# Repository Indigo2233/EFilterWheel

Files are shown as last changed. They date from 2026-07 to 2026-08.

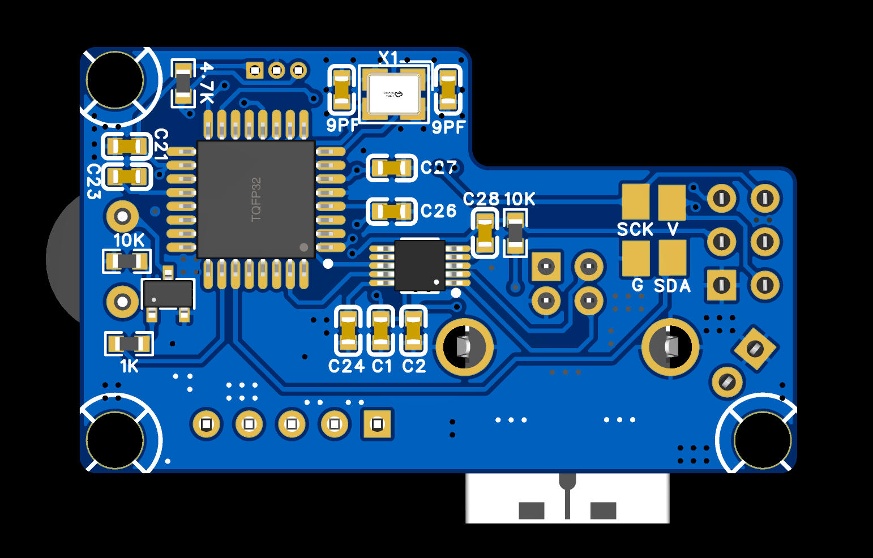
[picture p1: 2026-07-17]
ref/3、焊接参考_反面.jpg

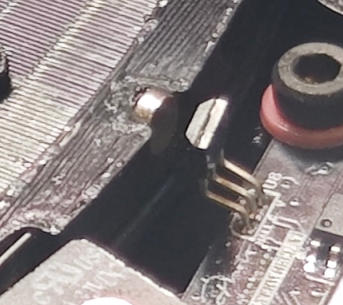
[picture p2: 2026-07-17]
ref/3、传感器安装参考.jpg

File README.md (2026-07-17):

# EFilterWheel — DIY 电动滤镜轮

基于 3D 打印结构的可重复定位电动滤镜轮，支持 Arduino Nano (USB 串口) 和 ESP8266 (Wi-Fi / ASCOM Alpaca) 两种主控配置。

## 功能

- ✅ 7 位 × 36mm 或 5 位 × 2" 滤镜盘
- ✅ 摩擦轮传动，28BYJ-48 步进电机 + ULN2003A 驱动
- ✅ 霍尔传感器原点 + 微动开关独立校验
- ✅ 上电自动回零，断电位置记忆 (EEPROM)
- ✅ 非阻塞运动控制 + 加减速
- ✅ ASCII 串口协议 (57600 baud)
- ✅ ASCOM Alpaca HTTP API (ESP8266)
- ✅ Web 控制页面 (ESP8266)
- ✅ N.I.N.A. 兼容

## 项目结构

```
EFilterWheel/
├── platformio.ini              # PlatformIO 构建配置
├── firmware/
│   ├── common/                 # 共享代码 (HAL, 运动, 滤镜轮, 协议)
│   │   ├── config.h            # 全局配置与引脚映射
│   │   ├── hal.h / hal.cpp     # 硬件抽象层
│   │   ├── motion.h / motion.cpp      # 步进电机控制
│   │   ├── wheel.h / wheel.cpp        # 滤镜轮状态机
│   │   ├── eeprom_config.h / .cpp     # EEPROM 配置存储
│   │   └── transport.h / transport.cpp # 串口/网络协议
│   ├── nano/
│   │   └── main.cpp            # Arduino Nano 入口
│   └── esp8266/
│       └── main.cpp            # ESP8266 入口 (含 Web/Alpaca)
├── tools/
│   └── serial_test.py          # PC 串口测试工具
├── docs/
│   └── protocol.md             # 协议文档
├── plan.md                     # 实施计划
└── README.md
```

## 快速开始

### 硬件要求

- 主控: Arduino Nano (ATmega328P) **或** Wemos D1 mini (ESP8266) —— 二选一
- 电机: 28BYJ-48 5V 减速步进电机
- 驱动: ULN2003A 模块
- 传感器: 霍尔开关 (开集电极输出, 如 A3144) + 微动开关
- 电源: 5V / 1A+ (建议 2A 适配器留余量)
- 蜂鸣器: Nano 可用, ESP8266 不可用 (无安全 GPIO)

### 接线 — Arduino Nano

| 功能 | Nano 引脚 | 连接至 |
|---|---|---|
| 电机 IN1 | D4 | ULN2003A IN1 |
| 电机 IN2 | D5 | ULN2003A IN2 |
| 电机 IN3 | D6 | ULN2003A IN3 |
| 电机 IN4 | D7 | ULN2003A IN4 |
| 霍尔传感器 | D2 | 霍尔 OUT (上拉至 5V) |
| 微动开关 | D3 | 开关 NO → D3, COM → GND |
| 蜂鸣器 | D8 | 蜂鸣器 + (仅 Nano) |
| LED | D13 | 板载 |

### 接线 — ESP8266 (Wemos D1 mini)

> ⚠️ **ESP8266 是 3.3V 器件，所有 GPIO 只耐受 3.3V！**
> 好消息：霍尔和微动开关都是"开漏/触点"型，**不需要电平转换芯片**，只需把上拉电阻接到 3.3V 即可。

**为什么不需要电平转换？**

```
Nano (5V) 接法:                     ESP8266 (3.3V) 接法:
                                     ⚠️ 错误:              ✅ 正确:
VCC(5V)                               VCC(5V)               VCC(5V)
  │                                      │                     │
  ├─ 4.7kΩ ──┬── GPIO(D2)               ├─ 4.7kΩ ──┬── GPIO   ├─ 霍尔 VCC(5V)
  │          │                           │          │          │
霍尔 OUT ────┘               →         霍尔 OUT ────┘        霍尔 OUT ────┬── GPIO(D7)
  │                                      │                     │          │
 GND                                    GND                    └─ 4.7kΩ ── 3.3V
                                                               │
霍尔是开集电极输出:                  上拉接 5V → GPIO 承受 5V   上拉接 3.3V → GPIO
OUT 脚只拉低,不输出高电平              ❌ 烧 GPIO!              最多承受 3.3V ✅
```

- **霍尔传感器**：开集电极（Open-Collector）输出。OUT 引脚只负责"拉低到 GND"，**高电平完全由上拉电阻的电压决定**。把上拉接到 3.3V，GPIO 就永远看不到 5V。
- **微动开关**：纯机械触点，一端接 GPIO，一端接 GND。用 3.3V 上拉，按下时读到 LOW，松开时读到 3.3V。

**实际操作：**

```
Wemos D1 mini 引脚:
                        ┌──────────────┐
                        │  3V3    GND  │ ← 用这俩
                        │  D0(16) D4(2)│
          4.7kΩ         │  D5(14) D3(0)│
3.3V ──/\/\/\/──┬── D7(13)            │
                │                      │
     霍尔 OUT ──┘                      │
                │                      │
          4.7kΩ │                      │
3.3V ──/\/\/\/──┬── D0(16)            │
                │                      │
    微动 NO ────┘                      │
                │                      │
     微动 COM ── GND                   │
                        └──────────────┘
```

- 在 D7 和 3V3 之间焊一个 4.7kΩ 电阻
- 在 D0 和 3V3 之间焊一个 4.7kΩ 电阻
- 霍尔 VCC 仍接 5V（传感器需要 5V 供电），OUT 接 D7
- 微动 NO 接 D0, COM 接 GND
- **不需要任何电平转换模块**

**引脚映射：**

| 功能 | GPIO | D1 mini 丝印 | 连接至 | 注意事项 |
|---|---|---|---|---|
| 电机 IN1 | 5 | D1 | ULN2003A IN1 | |
| 电机 IN2 | 4 | D2 | ULN2003A IN2 | |
| 电机 IN3 | 14 | D5 | ULN2003A IN3 | |
| 电机 IN4 | 12 | D6 | ULN2003A IN4 | |
| 霍尔传感器 | 13 | D7 | 霍尔 OUT | **必须接 3.3V 上拉电阻 (4.7kΩ)** |
| 微动开关 | 16 | D0 | 开关 NO → D0, COM → GND | **必须接外部 3.3V 上拉电阻** |
| LED | 2 | D4 | 板载 | 板载 LED, 低电平点亮 |
| 蜂鸣器 | — | — | **不接** | GPIO15(D8) 启动需 LOW, 无安全引脚可用 |

**电平处理要点：**

- **霍尔传感器**：VCC 接 **5V**（传感器供电），OUT 接 GPIO，上拉电阻接 **3.3V**
- **微动开关**：GPIO16 无内部上拉，外加 4.7kΩ 到 3.3V
- **ULN2003A**：数据手册输入高电平阈值 ≥ 2.4V，ESP8266 的 3.3V GPIO 满足要求；若驱动力不足可将 COM 端接 5V
- **不需要额外的电平转换芯片或分压电路**

**GPIO 启动约束（必须遵守）：**

| GPIO | 启动要求 | 当前用途 | 安全性 |
|---|---|---|---|
| GPIO0 (D3) | 必须 HIGH | 未使用 | ✅ |
| GPIO2 (D4) | 必须 HIGH | 板载 LED (已有上拉) | ✅ |
| GPIO15 (D8) | 必须 LOW | 未使用 | ✅ |
| GPIO16 (D0) | 无约束 | 微动开关输入 | ✅ |

### ESP8266 焊接步骤

参考图片：`ref/3、焊接参考_正面.jpg` 和 `ref/3、焊接参考_反面.jpg`

1. **先焊贴片、后焊插件** — 优先焊完所有贴片元件，再处理直插元件
2. **电机插座** — 5Pin 带锁插座，注意方向避免反插
3. **传感器连接** — 霍尔用 2Pin/3Pin 带锁插座；微动开关引脚可压弯
4. **上拉电阻** — 在霍尔和微动开关旁边就近焊接 4.7kΩ 上拉电阻到 3.3V
5. **不要焊蜂鸣器** — 无安全 GPIO
6. **电容** — 未标注容值的均为 100nF；电机驱动旁路电容 100~470µF
7. **保险丝** — 自恢复保险丝可选但建议焊接；不焊则短接焊盘
8. **TVS/肖特基二极管** — 丝印有横杠的一端为负极，对齐 PCB 丝印
9. **固定螺丝** — 轻微拧紧即可，务必放垫片防止磨损 PCB
10. **上电前检查** — 用万用表确认所有传感器引脚电压 ≤ 3.3V

### 编译与烧录

**PlatformIO**:

```bash
# Arduino Nano
pio run -e nano -t upload

# ESP8266
pio run -e esp8266 -t upload

# 串口监视
pio device monitor -b 57600
```

**Arduino IDE**:

1. 将 `firmware/common/` 中的 `.cpp` 和 `.h` 文件复制到 Sketch 目录
2. Nano: 将 `firmware/nano/main.cpp` 重命名为 `.ino` 并打开
3. ESP8266: 将 `firmware/esp8266/main.cpp` 重命名为 `.ino`，需安装 ESP8266 板支持包
4. 选择对应板型: Nano (ATmega328P) 或 Wemos D1 R1
5. 编译并上传

### 首次使用

1. 上电后设备自动开始回零
2. 串口终端 (57600 baud) 发送 `ID?` 验证通信
3. 发送 `STATE?` 确认状态为 `READY`
4. 发送 `GOTO 0` 移动到第一个槽位

### 标定

每台设备需要独立标定，因为打印收缩率和电机减速比存在差异：

```bash
# 设置滤镜盘槽位数
SLOTS 7

# 标定各槽位步数（从原点起算）
CAL SLOT 0 0
CAL SLOT 1 512
CAL SLOT 2 1024
# ...

# 保存配置
SAVE
```

## ESP8266 网络功能

ESP8266 首次上电时启动 AP 模式用于 Wi-Fi 配置：

1. 连接 WiFi `EFilterWheel-Setup` (密码: `filterwheel`)
2. 浏览器访问 `http://192.168.4.1/wifi`
3. 输入路由器 SSID 和密码
4. 设备重启后自动连接

设备就绪后：
- Web 控制: `http://<ip>/`
- Alpaca API: `http://<ip>/api/v1/filterwheel/0/`
- mDNS: `http://efilterwheel.local/`

## 许可证

本项目代码基于参考项目的非商业授权许可。个人制作、学习和非营利协作可按许可进行。商业用途需取得原作者书面授权。

原始项目作者: Eric (微信: ericbo)

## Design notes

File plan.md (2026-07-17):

# ESP8266 / Arduino Nano 电动滤镜轮实施计划

更新日期：2026-07-17  
参考资料：`E:\download\滤镜轮项目开源资料`

## 1. 项目目标

基于现有 3D 打印结构制作一套可重复定位的电动滤镜轮，支持以下两种主控构建配置：

- Arduino Nano：用于首个样机，通过 USB 串口连接计算机，优先完成机械、传感器和运动控制验证。
- ESP8266：用于网络控制版本，复用同一套运动控制逻辑，增加 Web 配置及 ASCOM Alpaca 接口。

两种主控为互斥配置，每台成品安装其中一种。首轮目标采用 Arduino Nano，原因是其 5 V I/O、USB 串口和原结构中的 ULN2003A/5 线步进电机组合适配度较高。

项目完成时应交付：

1. 可装配的机械结构及打印参数。
2. 原理图、接线图、BOM 和主控安装方案。
3. Arduino Nano 与 ESP8266 两个固件构建目标。
4. USB 串口控制协议及 ESP8266 网络接口。
5. ASCOM/Alpaca 兼容层和 N.I.N.A. 联调记录。
6. 校准、装配、烧录、故障处理和测试文档。

## 2. 已确认的参考基线

### 2.1 机械模型

| 模型 | 已提取外形尺寸 | 用途与检查重点 |
| --- | --- | --- |
| `7x36mm滤镜盘.STL` | 143 × 143 × 7 mm | 7 位、36 mm 滤镜；核对槽位中心与传感触发结构 |
| `5×2“滤镜盘.stl` | 143 × 143 × 7 mm | 5 位、2 英寸滤镜；核对滤镜实际外径和压环 |
| `外壳.STL` | 158 × 182.23 × 17 mm | 检查盘体间隙、遮光和主控空间 |
| `后盖.STL` | 158 × 182.59 × 5 mm | 检查螺丝长度、线束和主控高度 |
| `电机盖.STL` | 49.05 × 43.03 × 23 mm | 检查电机、接插件和线束空间 |
| `滤镜压环.STL` | 128.34 × 128.32 × 1 mm | 检查滤镜固定和翘曲 |
| `传动轮2_D轴.STL` | 11 × 11 × 8 mm | D 形电机轴适配候选 |
| `传动轮2_D14` 至 `D17` | 外径 14–17 mm，高 8 mm | 补偿打印收缩与摩擦圈预紧量 |
| `防脱压片.stl` | 33 × 33 × 3 mm | 中心轴防脱和轴向间隙控制 |
| `PCB螺丝垫片.STL` | 4.8 × 4.8 × 1 mm | 防止 PCB 与打印件接触磨损 |

参考 3MF 的现有切片参数为：PLA、0.4 mm 喷嘴、0.2 mm 层高、2 道墙、15% 网格填充、5 层顶面、3 层底面、关闭支撑、5 mm 自动裙边。首个尺寸样件沿用这组参数，传动轮应分别打印多个直径版本进行实配。

### 2.2 原结构的机电特征

根据项目介绍、内部结构图和焊接参考图，当前基线包含：

- 5 线单极步进电机和 ULN2003A 驱动阵列，具体电机型号及线圈参数需通过 BOM 和实物测量确认。
- 摩擦轮传动，传动轮通过橡胶圈压紧滤镜盘外缘。
- 一个霍尔传感器和一个磁铁，磁铁安装要求为 S 极朝外。
- 一个微动开关，预期用于槽位触发或独立位置校验，其实际触发规律应在手动旋转滤镜盘时记录。
- USB 接口、蜂鸣器、电源保护器件和 5 线电机插座。
- 上电初始化、位置检测和 ASCOM 控制属于原项目已说明的功能。

### 2.3 使用许可

参考资料采用仅限非商业用途的自定义许可。个人制作、学习和非营利协作可按许可进行；再发布模型、固件或修改版本时必须保留原许可与作者版权信息。商业用途需要取得作者书面授权。

## 3. 总体技术方案

```text
5 V 输入
  ├─ 保险/反接保护/TVS/滤波
  ├─ 主控：Arduino Nano 或 ESP8266
  └─ ULN2003A → 5 线步进电机 → 摩擦轮 → 滤镜盘

霍尔传感器 ──→ 原点输入
微动开关   ──→ 槽位索引或独立校验输入
USB 串口   ──→ Nano 控制协议 ──→ ASCOM 兼容层
Wi-Fi      ──→ ESP8266 HTTP/Alpaca 接口
```

固件分为四层：

1. `hal`：GPIO、定时器、EEPROM、串口和网络适配。
2. `motion`：步进序列、加减速、方向、超时和断电释放。
3. `wheel`：回零、槽位换算、误差补偿、状态机和故障处理。
4. `transport`：串口命令、Web 配置和 Alpaca API。

运动状态统一定义为 `BOOT`、`HOMING`、`READY`、`MOVING`、`ERROR`。所有移动操作均应设置最大步数和超时时间，故障状态应立即停止脉冲并释放电机线圈。

## 4. 电气设计计划

### 4.1 首轮器件基线

- 主控：Arduino Nano ATmega328P 兼容板。
- 网络主控候选：Wemos D1 mini 或同尺寸 ESP8266 开发板，最终型号由安装空间决定。
- 电机：参考原结构的 5 V、5 线减速步进电机候选，优先核对是否为 28BYJ-48 及其减速比。
- 驱动：ULN2003A 模块或自制小板；ESP8266 配置需实测 3.3 V 输入驱动余量。
- 原点传感器：开集电极霍尔开关候选，具体型号以原 BOM/丝印为准。
- 位置传感器：常开或常闭微动开关，先测定原机械触发方式。
- 电源：稳压 5 V、持续电流至少 1 A，建议预留 2 A 电源适配器余量。
- 保护与滤波：自恢复保险丝、反接保护、TVS、主控附近 100 nF 去耦和电机驱动附近 100–470 µF 储能电容。
- 连接：电机采用带锁 5Pin 插座，传感器采用带锁 2Pin/3Pin 插座，避免装配时反插。

### 4.2 候选引脚分配

Arduino Nano：

| 功能 | 引脚 | 说明 |
| --- | --- | --- |
| 霍尔原点 | D2 | 外部中断、内部或外部上拉 |
| 微动开关 | D3 | 外部中断、软硬件消抖 |
| 电机 IN1–IN4 | D4–D7 | 连接 ULN2003A |
| 蜂鸣器 | D8 | 通过限流或三极管驱动 |
| 状态灯 | D13 | 使用板载 LED |
| USB 串口 | D0/D1 | 仅用于板载 USB 串口，不接其他负载 |

ESP8266 候选：

| 功能 | GPIO | 说明 |
| --- | --- | --- |
| 电机 IN1–IN4 | 5、4、14、12 | 对应常见 D1、D2、D5、D6 标记 |
| 霍尔原点 | 13 | 中断输入，使用 3.3 V 上拉 |
| 微动开关 | 16 | 轮询输入并进行消抖 |

ESP8266 的传感器输入电压必须限制在 3.3 V。若霍尔器件为开集电极输出，将上拉电阻接至 3.3 V；若输出结构或型号无法确认，应增加分压、钳位或电平转换。GPIO0、GPIO2 和 GPIO15 与启动模式有关，首版接线应避免传感器改变其上电电平。

### 4.3 原理样机检查

1. 在滤镜轮外部搭建电机、ULN2003A 和主控。
2. 测量单相、双相和堵转时的 5 V 电流及主控电压跌落。
3. 确认电机线序、转向、半步序列、最大可靠速度和启动速度。
4. 分别测量霍尔传感器有磁/无磁电平，确认磁铁极性和有效距离。
5. 记录微动开关在完整一圈内的触发次数、触发宽度和对应槽位。
6. 验证电机停机后释放线圈不会导致滤镜盘自行偏移。

## 5. 机械实施计划

### 阶段 M1：模型复核

1. 确定首个滤镜盘版本，默认采用 `7x36mm滤镜盘.STL`。
2. 在切片软件中检查所有模型的单位、法向、薄壁、孔径和打印方向。
3. 测量现有电机轴、橡胶圈、磁铁、微动开关、螺丝和滤镜的实际尺寸。
4. 先打印 D14–D17 传动轮、PCB 垫片和一段局部配合测试件。
5. 选定能够稳定传动且不会显著压缩橡胶圈的传动轮尺寸。

### 阶段 M2：空载装配

1. 打印外壳、后盖、电机盖、滤镜盘、防脱压片和压环。
2. 安装空滤镜盘，调整中心轴向间隙，使盘体能够手动平稳旋转。
3. 检查盘体全周与外壳、后盖、螺丝、传感器和线束的间隙。
4. 调整电机位置和摩擦轮预紧量，记录可重复的装配尺寸。
5. 确定 Nano 与 ESP8266 各自的安装支架、USB 开口和走线方案。

### 阶段 M3：负载装配

1. 安装测试配重或低价值滤镜，检查盘体翘曲和压环受力。
2. 完成所有槽位的光轴中心校验。
3. 对外壳接缝、USB 开口和螺丝孔实施遮光检查。
4. 通过连续换位试验确认橡胶圈无打滑、啃边和明显磨耗。

## 6. 固件实施计划

### 阶段 F1：电机与传感器最小程序

- 实现 4 相半步驱动表、方向控制和非阻塞定时步进。
- 实现速度参数、启动斜坡和停机线圈释放。
- 输出霍尔和微动开关原始状态、消抖状态及触发计数。
- 提供安全停止和移动超时。

### 阶段 F2：回零与槽位标定

- 上电进入 `HOMING`，以低速搜索霍尔原点。
- 首次触发后退出传感区，再以更低速度二次接近，减少回零方向误差。
- 测量完整一圈的总步数和各槽位对应步数，分别保存 5 位、7 位配置。
- 记录微动开关触发点与霍尔原点的关系，确定其作为逐槽索引或独立校验信号的用途。
- 将槽位数、原点偏移、方向、速度、超时及补偿参数保存到 EEPROM，并附带版本号和校验值。

### 阶段 F3：定位算法与状态机

- 实现 `gotoSlot(n)`，支持 5 位和 7 位盘体。
- 计算顺时针和逆时针路径，默认采用较短路径。
- 通过固定方向终到或受控过冲回退处理齿隙、摩擦回差和开关迟滞，最终方案由重复定位数据决定。
- 在运动中报告忙状态，完成后报告实际槽位；传感异常、超时和步数越界进入 `ERROR`。
- 上电、复位、通信重连后执行可配置的回零流程。
- 启用看门狗，并确保 ESP8266 在电机运动期间持续让出网络任务执行时间。

### 阶段 F4：统一控制协议

定义换行结束的 ASCII 协议，首版命令如下：

| 命令 | 作用 |
| --- | --- |
| `ID?` | 返回设备、固件和协议版本 |
| `STATE?` | 返回 `HOMING/READY/MOVING/ERROR` 及错误码 |
| `POS?` | 返回当前槽位；移动中返回 `-1` |
| `HOME` | 启动回零 |
| `GOTO n` | 移动到从 0 开始编号的槽位 |
| `STOP` | 安全停止并进入需确认的状态 |
| `SLOTS 5` / `SLOTS 7` | 设置滤镜盘槽位数 |
| `CAL ...` | 设置或查询标定参数 |
| `SAVE` | 保存有效配置 |

响应格式统一为 `OK ...` 或 `ERR <code> <message>`。Nano 默认串口参数先采用参考项目使用的 57600 baud，完成稳定性测试后冻结协议版本。

### 阶段 F5：ESP8266 网络功能

- 实现 Wi-Fi 初次配置、凭据保存、断线重连和恢复出厂设置。
- 提供本地状态页、手动回零、槽位选择和标定参数页面。
- 将 HTTP 请求转入同一运动状态机，禁止网络回调直接驱动电机。
- 实现 ASCOM Alpaca FilterWheel 所需接口及设备发现。
- 保留串口日志，并提供网络故障时的本地控制入口。

## 7. 上位机与天文软件兼容计划

### 7.1 Arduino Nano 路线

1. 先制作串口测试工具或命令行脚本，覆盖所有命令和错误码。
2. 明确原项目 ASCOM 驱动的串口协议；可兼容时复用协议，不兼容时开发新的 ASCOM FilterWheel 驱动或本地 Alpaca 桥接程序。
3. 在 N.I.N.A. 中验证连接、回零、槽位切换、序列切换和异常恢复。

### 7.2 ESP8266 路线

1. 按 ASCOM Alpaca FilterWheel 接口实现 `Names`、`FocusOffsets` 和 `Position` 等必要成员。
2. 槽位编号使用 0 到 N−1；运动期间 `Position` 返回 `-1`，完成后返回实际槽位。
3. 验证设备发现、并发查询、重复命令、网络中断和主控复位场景。

ASCOM 当前的 COM 与 Alpaca 主接口采用相同的设备语义，FilterWheel 的位置写入应异步启动运动，客户端通过 `Position == -1` 判断移动状态。实现时以官方规范为准：

- https://ascom-standards.org/newdocs/
- https://ascom-standards.org/newdocs/filterwheel.html
- https://ascom-standards.org/AlpacaDeveloper/ASCOMAlpacaAPIReference.html

## 8. 验证与验收标准

### 8.1 台架测试

- 电机连续正反转各 30 分钟，无主控复位、驱动过热和持续丢步。
- 霍尔传感器与微动开关各触发 500 次，无漏触发和重复计数。
- 任意角度启动回零 50 次，成功率 100%。
- 移动超时、传感器常开、传感器常闭和电机断线均产生明确错误码。

### 8.2 整机定位测试

- 5 位或 7 位全部槽位往返切换至少 200 个完整循环。
- 每个槽位从两个方向到达后，滤镜孔相对光轴中心偏差目标值不超过 0.5 mm。
- 测试过程中不允许出现摩擦轮打滑、滤镜盘刮擦和紧固件松动。
- 相邻槽位切换时间目标值不超过 10 秒；最终指标依据电机减速比和可靠速度实测冻结。
- 上电到完成回零的目标时间不超过 30 秒。
- 停机 30 分钟后电机、驱动器和主控温升处于器件允许范围，并记录实测温度。

### 8.3 通信测试

- USB 插拔、串口占用、错误命令和连续快速查询不会导致固件失去响应。
- ASCOM/N.I.N.A. 连续执行 100 次槽位切换，槽位显示与实际位置一致。
- ESP8266 经过 Wi-Fi 断开、路由器重启和 DHCP 地址变化后能够自动恢复。
- 运动过程中网络请求保持可响应，所有重复请求具有确定行为。

## 9. 分阶段交付与退出条件

| 阶段 | 主要产物 | 退出条件 |
| --- | --- | --- |
| P0 资料与需求冻结 | 选型记录、尺寸表、原 BOM 复核结果 | 确定滤镜盘版本、主控首选、电机型号和传感器逻辑 |
| P1 台架电气样机 | 接线图、电流/电平记录、最小测试程序 | 电机与两个传感器稳定运行 |
| P2 Nano 运动固件 | 回零、定位、协议、EEPROM 配置 | 空载定位测试通过 |
| P3 机械整机 | 完整打印件、安装支架、装配记录 | 负载 200 循环测试通过 |
| P4 USB 软件兼容 | 串口工具、ASCOM 兼容层、联调记录 | N.I.N.A. 自动序列切换通过 |
| P5 ESP8266 版本 | 网络配置、Web 页面、Alpaca 服务 | 网络恢复及 Alpaca 测试通过 |
| P6 定版 | BOM、原理图、固件发布包、制作说明 | 全部验收项目完成并保留许可信息 |

## 10. 主要风险与处理措施

| 风险 | 影响 | 处理措施 |
| --- | --- | --- |
| 原 BOM 尚未完成单元格级复核 | 电机、霍尔器件和保护元件型号存在偏差 | 在 P0 使用可控的表格读取工具复核 BOM，并用实物丝印和电气测量交叉确认 |
| 摩擦轮预紧量不稳定 | 打滑、磨耗、定位误差 | 打印 D14–D17 多个版本，记录压缩量，建立固定电机安装尺寸 |
| 5 线电机减速比存在批次差异 | 每圈步数和速度不一致 | 每台设备执行整圈标定，参数写入 EEPROM |
| 微动开关用途判断错误 | 槽位计数逻辑失效 | 手动旋转一周记录波形，再冻结传感器职责 |
| ESP8266 3.3 V 电平与原 5 V 传感器不兼容 | GPIO 损坏或误触发 | 使用 3.3 V 上拉、电平转换和输入保护，装机前测量所有输入电压 |
| 电机电流引起主控复位 | 丢失位置和网络断线 | 星形供电、驱动端储能电容、去耦、线束分离和电压跌落测试 |
| 打印收缩与盘体翘曲 | 摩擦增大、光轴偏移 | 先打印测试件，必要时提高墙数、调整材料和打印方向 |
| 网络控制功能占用实时执行时间 | 步进不均匀或看门狗复位 | 使用定时调度、非阻塞状态机和短网络回调 |
| 参考资料为非商业许可 | 再发布或用途受限 | 保留许可和版权声明，商业计划启动前取得书面授权 |

## 11. 实施前需要冻结的选择

以下默认值可直接进入 P0：

- 首个机械版本：7 × 36 mm 滤镜盘。
- 首个主控：Arduino Nano。
- 首个连接方式：USB 串口，57600 baud。
- 电机基线：5 V、5 线减速步进电机，型号在 P0 复核。
- 传感方案：霍尔原点加微动开关独立校验。
- 网络版本：完成 Nano 整机验收后移植至 ESP8266。

如果实际目标为 5 × 2 英寸滤镜、仅需 Wi-Fi 控制、需要兼容现有原版 ASCOM 驱动，或已经购买了特定电机/开发板，应在 P0 开始时更新上述选择。

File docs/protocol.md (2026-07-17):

# EFilterWheel 串口控制协议 v1.0

## 概述

EFilterWheel 使用基于换行 (`\n`) 分隔的 ASCII 文本协议进行串口通信。

- **物理层**: UART, 57600 baud, 8N1
- **命令格式**: `CMD [args]\n`
- **响应格式**: `OK [data]\n` 或 `ERR <code> <message>\n`
- **编码**: UTF-8

## 设备状态

| 状态 | 含义 | 可接受命令 |
|---|---|---|
| `BOOT` | 启动中 | 无 |
| `HOMING` | 回零中 | `STATE?`, `POS?`, `ID?`, `STOP` |
| `READY` | 就绪 | 全部命令 |
| `MOVING` | 移动中 | `STATE?`, `POS?`, `ID?`, `STOP` |
| `ERROR` | 错误 | `STATE?`, `ID?`, `RESET` |

## 命令参考

### ID? — 查询设备信息

```
> ID?
< OK EFilterWheel-Nano FW:1.0.0 PROTO:1.0
```

### STATE? — 查询设备状态

```
> STATE?
< OK READY ERR:0
```

错误码为 0 表示无错误，其他值见错误码表。

### POS? — 查询当前槽位

```
> POS?
< OK 2
```

- `0..N-1`: 当前槽位号（从 0 开始）
- `-1`: 移动中
- `-2`: 未回零

### HOME — 启动回零

```
> HOME
< OK HOMING started
  ... (等待中)
< OK HOMED
```

回零过程：
1. 快速搜索霍尔传感器
2. 首次触发后退出传感区
3. 低速二次精调接近

回零超时默认 60 秒。

### GOTO n — 移动到槽位 n

```
> GOTO 3
< OK GOTO 3
```

- 槽位从 0 开始编号
- 自动选择最短路径
- 移动超时默认 30 秒

### STOP — 紧急停止

```
> STOP
< OK STOPPED
```

停止后设备进入 `ERROR` 状态，需要重新回零。

### SLOTS 5|7 — 设置滤镜盘槽位数

```
> SLOTS 5
< OK SLOTS=5
```

### CAL — 标定参数管理

查询当前标定：

```
> CAL?
< OK SLOTS:7 SPEED:800 DIR:CW INVERT:0 S0:0 S1:512 S2:1024 ...
```

设置槽位步数：

```
> CAL SLOT 1 500
< OK CAL SLOT 1 = 500
```

设置速度：

```
> CAL SPEED 1000
< OK CAL SPEED=1000
```

设置方向：

```
> CAL DIR CW
< OK CAL DIR=CW
```

设置原点偏移：

```
> CAL OFFSET 10
< OK CAL OFFSET=10
```

### SAVE — 保存配置到 EEPROM

```
> SAVE
< OK SAVED
```

### RESET — 重启设备

```
> RESET
< OK RESET - Rebooting...
```

### HELP — 显示命令帮助

```
> HELP
< OK Commands:
<   ID?        - Device info
<   STATE?     - Device state
  ...
< OK End of help
```

## 错误码

| 码 | 名称 | 说明 |
|----|---|---|
| 0 | ERR_NONE | 无错误 |
| 1 | ERR_UNKNOWN_CMD | 未知命令 |
| 2 | ERR_BAD_ARG | 参数错误 |
| 3 | ERR_NOT_READY | 设备未就绪 |
| 4 | ERR_BUSY | 设备忙 |
| 5 | ERR_HOMING_FAILED | 回零失败 |
| 6 | ERR_TIMEOUT | 移动超时 |
| 7 | ERR_SENSOR_FAULT | 传感器故障 |
| 8 | ERR_EEPROM_FAIL | EEPROM 故障 |
| 9 | ERR_INVALID_CONFIG | 无效配置 |
| 10 | ERR_MOTOR_FAULT | 电机故障 |
| 11 | ERR_STOPPED | 已停止 |
| 12 | ERR_OUT_OF_RANGE | 槽位超出范围 |
| 99 | ERR_INTERNAL | 内部错误 |

## ASCOM 兼容性

对于 Arduino Nano + USB 串口连接，可以通过 ASCOM 串口驱动或 Alpaca 桥接程序连接到 N.I.N.A.。

对于 ESP8266 版本，设备直接提供 ASCOM Alpaca FilterWheel HTTP API：

```
GET  /api/v1/filterwheel/0/position
PUT  /api/v1/filterwheel/0/position  (body: slot number)
GET  /api/v1/filterwheel/0/names
GET  /api/v1/filterwheel/0/focusoffsets
GET  /api/v1/filterwheel/0/connected
GET  /api/v1/filterwheel/0/interfaceversion
GET  /api/v1/filterwheel/0/driverinfo
```

Alpaca 设备发现通过 mDNS (`efilterwheel.local`) 实现。

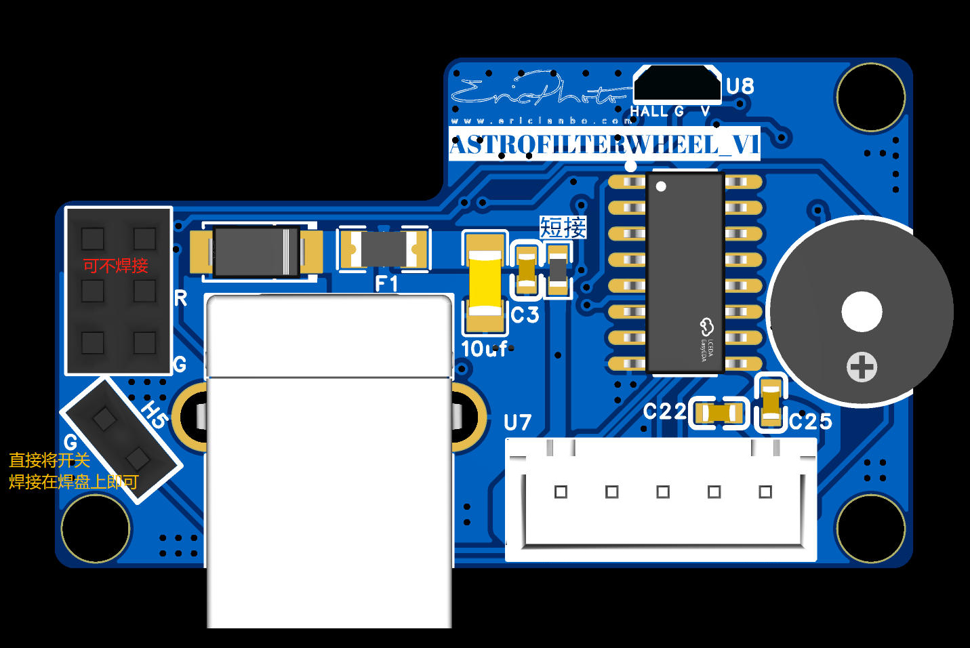
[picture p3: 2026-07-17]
ref/3、焊接参考_正面.jpg

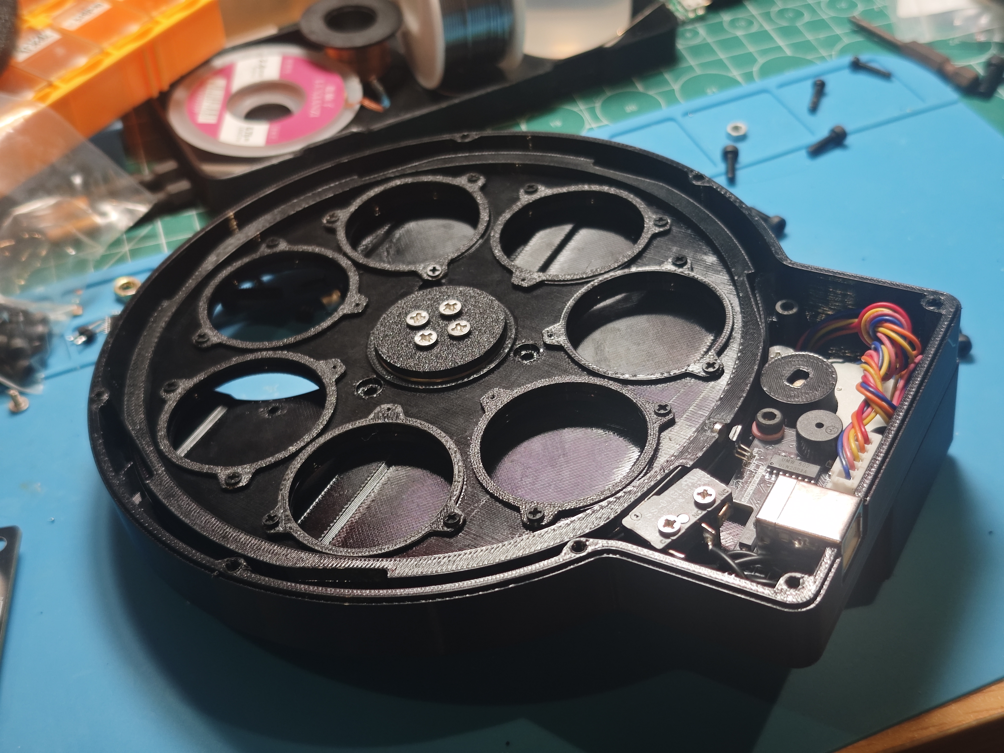
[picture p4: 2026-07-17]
ref/3、实物内部参考.jpg

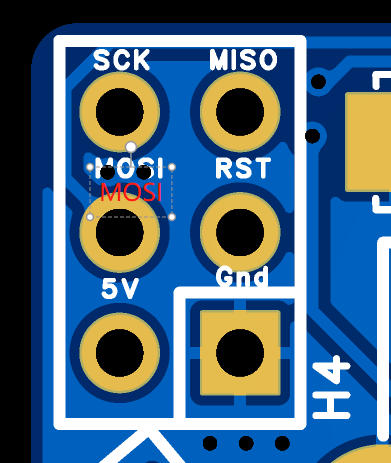
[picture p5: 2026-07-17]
ref/3、ISP烧录引脚参考.jpg

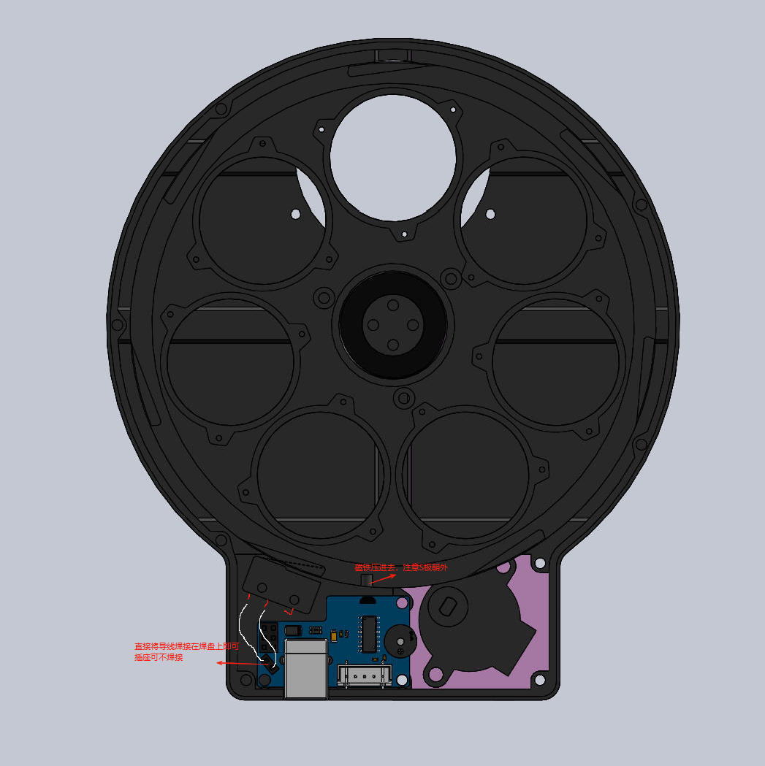
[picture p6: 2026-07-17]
ref/3、内部结构参考.jpg

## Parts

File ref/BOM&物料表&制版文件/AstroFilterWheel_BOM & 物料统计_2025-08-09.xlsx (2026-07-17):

No. |  | Quantity | Comment | Designator | Footprint
1 |  | 1 | 1K | 1K | R0603
2 |  | 1 | 4.7K | 4.7K | R0603
3 |  | 2 | 22pF | 9PF,9PF | C0603
4 |  | 1 | 10K | 10K | R0603
5 |  | 1 | 10kΩ | 10K | R0603
6 |  | 1 | 10UF | 10uf | C1206 | 0.5
7 |  | 1 | 3kHz | BUZZER1 | BUZ-TH_BD9.0-P5.00-D0.6-FD | 0.5
8 |  | 11 | 100nF | C1,C2,C3,C21,C22,C23,C24,C25,C26,C27,C28 | C0603 | 0.1
9 | 可不买 | 1 | SMD1206-150-16 | F1 | F1206 | 0.2
10 | 可不买 | 1 | 2.54mm2x3直排母 | H4 | HDR-TH_6P-P2.54-V-F-R2-C3-S2.54
11 |  | 1 | S8050 J3Y | Q1 | SOT-23-3_L3.0-W1.7-P0.95-LS2.9-BR
12 |  | 3 | M3螺丝 | SCREW1,SCREW2,SCREW3 | M3螺丝
13 | 可不买 | 1 | SMAJ6.0A-JSM | TVS1 | SMA_L4.3-W2.6-LS5.2-RD | 0.1
14 |  | 1 | ULN2003 | U4 | SOIC-16_L9.9-W3.9-P1.27-LS6.0-BL | 0.3
15 |  | 1 | ATMEGA328P-AU | U5 | TQFP-32_L7.0-W7.0-P0.80-LS9.0-BL | 9.3
16 | 注意型号 | 1 | CH340E | U6 | MSOP-10_L3.0-W3.0-P0.50-LS5.0-BL | 2.4
17 |  | 1 | WAFER-XH254Z-5A | U7 | CONN-TH_5P-P2.50_WAFER-XH254Z-5A
18 |  | 1 | A3144EUA-T-JSM | U8 | TO-92S-3_L4.1-W1.7-P1.27-L
19 |  | 1 | HX TYPE-BF 90 | USB1 | USB-B-TH_HX-TYPE-BF-90 | 0.15
20 |  | 1 | 16MHz | X1 | CRYSTAL-SMD_4P-L3.2-W2.5-BL | 0.2
21 |  | 1 | 短接 | 短接 | R0603
22 |  | 1 | 28BYJ48步进电机 |  |  | 3.9
23 |  | 2 | 磁铁 D4 X 1.5mm
24 | 用导线焊接在焊盘 | 1 | 微动开关SS-01GL |  |  | 0.5
25 |  | 1 | 外径130X1.9mm橡胶小皮圈 |  |  | 0.79
26 |  | 1 | F6903轴承 |  |  | 2.5
 |  |  |  |  | 合计总价： | 21.44
 | 所有标注可不买的元件都可选择性购买，不影响核心功能。
 | 注意型号不要买错，否则会导致无法焊接以及功能异常。

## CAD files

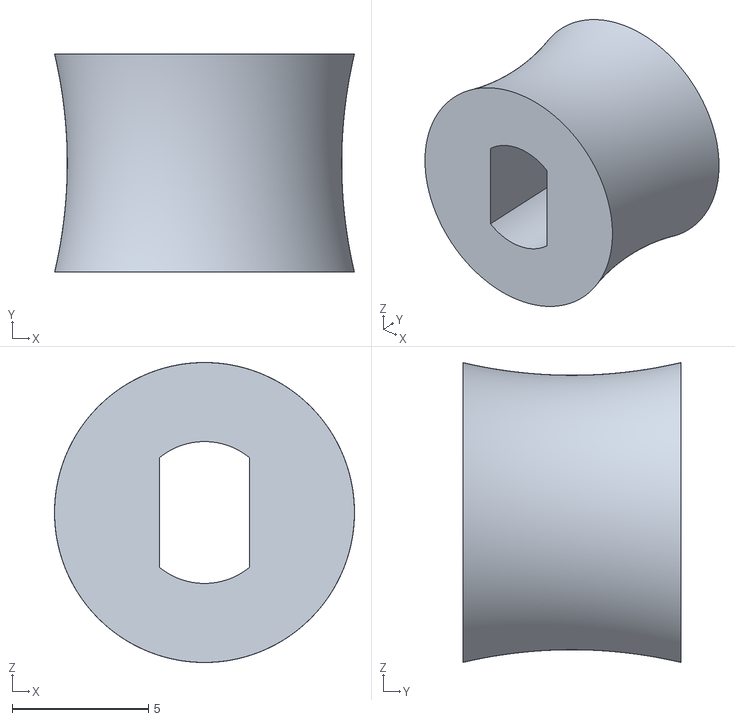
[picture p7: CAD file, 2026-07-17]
ref/3D打印模型文件/传动轮2_D轴.STL
11.0 x 8.00 x 11.0

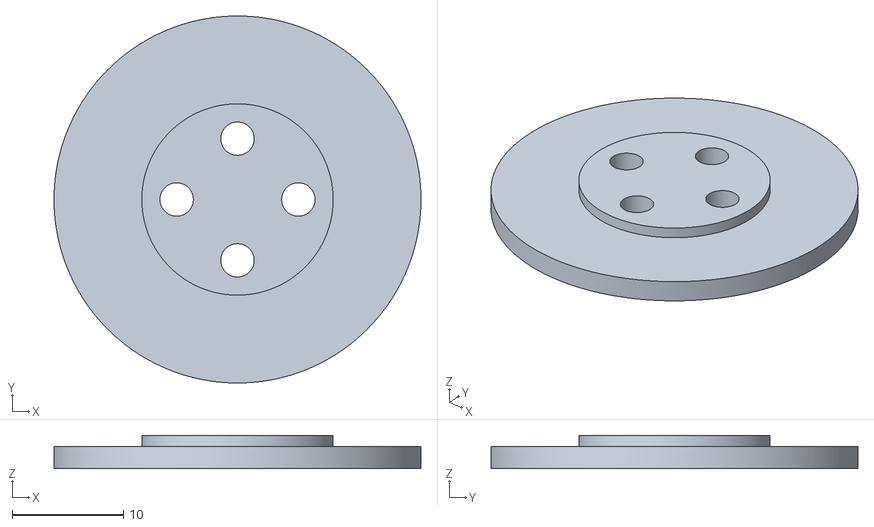
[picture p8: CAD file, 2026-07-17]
ref/3D打印模型文件/防脱压片.stl
33.0 x 33.0 x 3.00

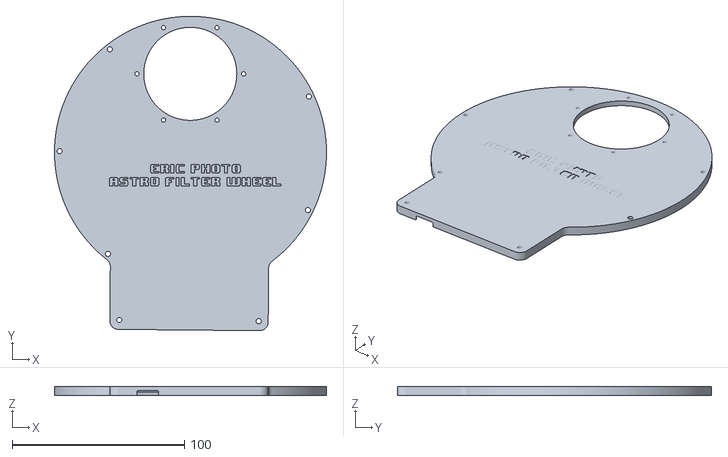
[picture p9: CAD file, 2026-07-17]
ref/3D打印模型文件/后盖.STL
158.0 x 182.6 x 5.00

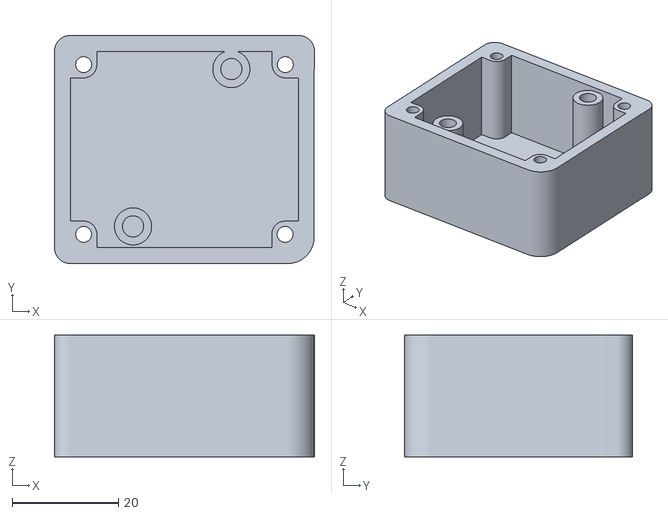
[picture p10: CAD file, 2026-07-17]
ref/3D打印模型文件/电机盖.STL
49.1 x 43.0 x 23.0

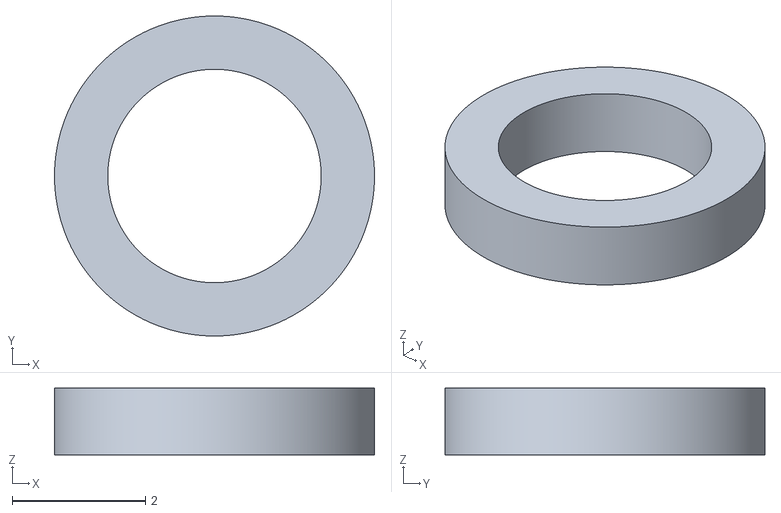
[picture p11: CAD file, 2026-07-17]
ref/3D打印模型文件/PCB螺丝垫片.STL
4.80 x 4.80 x 1.00

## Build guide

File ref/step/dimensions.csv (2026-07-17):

零件名 | 类型 | X(mm) | Y(mm) | Z(mm) | 体积(mm³) | 投影半径(mm) | 孔数 | 孔径(mm) | 壁厚(mm)
5×2“滤镜盘 | round_disk | 143.0 | 143.0 | 7.0 | 27033.58 | 79.23 | 1 | bottom:⌀33.11
7x36mm滤镜盘 | round_disk | 143.0 | 143.0 | 7.0 | 37542.79 | 88.33 | 0
PCB螺丝垫片 | generic | 4.8 | 4.8 | 1.0 | 10.05 | 2.4 | 0
传动轮2_D14 | cylinder | 14.0 | 8.0 | 14.0 | 987.48 | 8.06 | 0
传动轮2_D15 | cylinder | 15.0 | 8.0 | 15.0 | 1157.36 | 8.5 | 0
传动轮2_D16 | cylinder | 16.0 | 8.0 | 16.0 | 1339.19 | 8.94 | 0
传动轮2_D17 | cylinder | 17.0 | 8.0 | 17.0 | 1532.95 | 9.39 | 0
传动轮2_D轴 | cylinder | 11.0 | 8.0 | 11.0 | 549.54 | 6.8 | 0
后盖 | round_disk | 158.0 | 182.59 | 5.0 | 60507.78 | 96.92 | 1 | top:⌀14.06
外壳 | flat_plate | 158.0 | 17.0 | 182.23 | 102357.27 | 79.76 | 1 | top:⌀16.57
滤镜压环 | round_disk | 128.34 | 128.32 | 1.0 | 1902.9 | 65.32 | 0
电机盖 | cylinder | 49.05 | 43.03 | 23.0 | 17320.78 | 31.44 | 2 | top:⌀53.09; bottom:⌀52.94
防脱压片 | round_disk | 33.0 | 33.0 | 3.0 | 1858.1 | 16.5 | 2 | top:⌀13.94; bottom:⌀13.94

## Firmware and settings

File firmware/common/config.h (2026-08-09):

/**
 * @file config.h
 * @brief 滤镜轮全局配置与常量定义
 *
 * 本文件定义与平台无关的滤镜轮参数、引脚映射和协议常量。
 * 平台相关宏通过 PLATFORM_NANO / PLATFORM_ESP8266 区分。
 */

#ifndef CONFIG_H
#define CONFIG_H

#include <stdint.h>

/* =========================================================================
 * 固件版本
 * ========================================================================= */
#define FW_VERSION_MAJOR    1
#define FW_VERSION_MINOR    0
#define FW_VERSION_PATCH    0
#define FW_VERSION_STRING   "1.0.0"
#define PROTOCOL_VERSION    "1.0"

/* =========================================================================
 * 设备标识
 * ========================================================================= */
#if defined(PLATFORM_NANO)
  #define DEVICE_NAME        "EFilterWheel-Nano"
#elif defined(PLATFORM_ESP8266)
  #define DEVICE_NAME        "EFilterWheel-ESP8266"
#else
  #define DEVICE_NAME        "EFilterWheel"
#endif

/* =========================================================================
 * 滤镜盘参数
 * ========================================================================= */
#define MAX_SLOTS            7       ///< 最大槽位数（7位滤镜盘）
#define MIN_SLOTS            5       ///< 最小槽位数（5位滤镜盘）
#define DEFAULT_SLOTS        7       ///< 默认 7 位滤镜盘

/* =========================================================================
 * 运动参数
 * ========================================================================= */
#define DEFAULT_SPEED_PPS    800     ///< 默认脉冲频率 (Hz)
#define MIN_SPEED_PPS        200     ///< 最小脉冲频率
#define MAX_SPEED_PPS        2000    ///< 最大脉冲频率
#define HOMING_SPEED_PPS     300     ///< 回零初始速度
#define HOMING_FINE_SPEED_PPS 150    ///< 回零精调速度
#define RAMP_STEPS           50      ///< 加减速步数

#define MAX_STEPS_PER_MOVE   10000   ///< 单次移动最大步数
#define MOVE_TIMEOUT_MS      30000   ///< 移动超时 (ms)
#define HOMING_TIMEOUT_MS    60000   ///< 回零超时 (ms)

#define COIL_RELEASE_DELAY_MS 200    ///< 停机后线圈释放延迟 (ms)

/* =========================================================================
 * 传感器消抖
 * ========================================================================= */
#define HALL_DEBOUNCE_MS     5       ///< 霍尔传感器消抖 (ms)
#define SWITCH_DEBOUNCE_MS   10      ///< 微动开关消抖 (ms)

/* =========================================================================
 * EEPROM 地址布局
 * ========================================================================= */
#define EEPROM_MAGIC_ADDR    0       ///< 魔数地址 (2 bytes)
#define EEPROM_VERSION_ADDR  2       ///< 配置版本 (1 byte)
#define EEPROM_CHECKSUM_ADDR 3       ///< 校验和 (1 byte)
#define EEPROM_SLOTS_ADDR    4       ///< 槽位数 (1 byte)
#define EEPROM_SPEED_ADDR    5       ///< 速度 (2 bytes)
#define EEPROM_DIR_ADDR      7       ///< 方向 (1 byte)
#define EEPROM_HOME_OFFSET   8       ///< 原点偏移 (2 bytes)
#define EEPROM_SLOT_STEPS    10      ///< 各槽位步数起始 (MAX_SLOTS * 2 bytes)
#define EEPROM_CONFIG_SIZE   (EEPROM_SLOT_STEPS + MAX_SLOTS * 2)

#define EEPROM_MAGIC         0xA55A  ///< 配置魔数

/* =========================================================================
 * 错误码
 * ========================================================================= */
typedef enum {
    ERR_NONE            = 0,    ///< 无错误
    ERR_UNKNOWN_CMD     = 1,    ///< 未知命令
    ERR_BAD_ARG         = 2,    ///< 参数错误
    ERR_NOT_READY       = 3,    ///< 设备未就绪
    ERR_BUSY            = 4,    ///< 设备忙
    ERR_HOMING_FAILED   = 5,    ///< 回零失败
    ERR_MOTION_TIMEOUT  = 6,    ///< 移动超时
    ERR_SENSOR_FAULT    = 7,    ///< 传感器故障
    ERR_EEPROM_FAIL     = 8,    ///< EEPROM 读写失败
    ERR_INVALID_CONFIG  = 9,    ///< 无效配置
    ERR_MOTOR_FAULT     = 10,   ///< 电机故障
    ERR_STOPPED         = 11,   ///< 已停止
    ERR_OUT_OF_RANGE    = 12,   ///< 槽位超出范围
    ERR_INTERNAL        = 99,   ///< 内部错误
} error_code_t;

/* =========================================================================
 * 设备状态
 * ========================================================================= */
typedef enum {
    STATE_BOOT      = 0,    ///< 启动中
    STATE_HOMING    = 1,    ///< 回零中
    STATE_READY     = 2,    ///< 就绪
    STATE_MOVING    = 3,    ///< 移动中
    STATE_ERROR     = 4,    ///< 错误
} device_state_t;

/* =========================================================================
 * 运动方向
 * ========================================================================= */
typedef enum {
    DIR_CW   = 0,   ///< 顺时针
    DIR_CCW  = 1,   ///< 逆时针
} direction_t;

/* =========================================================================
 * 命令枚举
 * ========================================================================= */
typedef enum {
    CMD_ID          = 0,
    CMD_STATE       = 1,
    CMD_POS         = 2,
    CMD_HOME        = 3,
    CMD_GOTO        = 4,
    CMD_STOP        = 5,
    CMD_SLOTS       = 6,
    CMD_CAL         = 7,
    CMD_SAVE        = 8,
    CMD_RESET       = 9,
    CMD_HELP        = 10,
    CMD_UNKNOWN     = 0xFF,
} command_t;

/* =========================================================================
 * 蜂鸣器开关 (ESP8266 默认关闭: GPIO15 必须 LOW 才能正常启动)
 * ========================================================================= */
#if defined(PLATFORM_NANO)
  #define BUZZER_ENABLED   1     ///< Nano D8 安全, 蜂鸣器可用
#elif defined(PLATFORM_ESP8266)
  #define BUZZER_ENABLED   0     ///< ESP8266 无安全 GPIO, 关闭蜂鸣器
#endif

/* =========================================================================
 * 引脚映射 - Arduino Nano
 * ========================================================================= */
#if defined(PLATFORM_NANO)
  // 电机 4 相 (连接 ULN2003A)
  #define PIN_MOTOR_IN1   4
  #define PIN_MOTOR_IN2   5
  #define PIN_MOTOR_IN3   6
  #define PIN_MOTOR_IN4   7

  // 传感器
  #define PIN_HALL_SENSOR 2   ///< 霍尔原点 (INT0)
  #define PIN_LIMIT_SWITCH 3  ///< 微动开关 (INT1)

  // 执行器
  #if BUZZER_ENABLED
    #define PIN_BUZZER    8
  #endif
  #define PIN_LED         13  ///< 板载 LED (PB5)

  // 串口 (使用硬件 USART)
  #define SERIAL_BAUD     57600

/* =========================================================================
 * 引脚映射 - ESP8266 (Wemos D1 mini 标注)
 * 启动约束: GPIO0/GPIO2 需 HIGH, GPIO15 需 LOW
 * 已占用: GPIO5(D1)/GPIO4(D2)/GPIO14(D5)/GPIO12(D6)/GPIO13(D7)
 * ========================================================================= */
#elif defined(PLATFORM_ESP8266)
  // 电机 4 相
  #define PIN_MOTOR_IN1   5   ///< D1 (安全)
  #define PIN_MOTOR_IN2   4   ///< D2 (安全)
  #define PIN_MOTOR_IN3   14  ///< D5 (安全)
  #define PIN_MOTOR_IN4   12  ///< D6 (安全)

  // 传感器
  #define PIN_HALL_SENSOR 13  ///< D7 (安全, 需外部 3.3V 上拉)
  #define PIN_LIMIT_SWITCH 16 ///< D0 (无内部上拉, 需外部上拉电阻)

  // 执行器 (蜂鸣器已禁用: 无安全 GPIO 可用)
  #define PIN_LED         2   ///< D4 板载 LED (GPIO2, 启动需 HIGH, 已有外部上拉)

  // 传感器电压域
  #define SENSOR_VOLTAGE  3.3f

  #define SERIAL_BAUD     57600
#endif

/* =========================================================================
 * 宏工具
 * ========================================================================= */
#define ARRAY_SIZE(arr)  (sizeof(arr) / sizeof((arr)[0]))

#endif // CONFIG_H

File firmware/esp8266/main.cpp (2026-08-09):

/**
 * @file main.cpp
 * @brief ESP8266 (Wemos D1 mini) 滤镜轮固件入口
 *
 * 在 Arduino Nano 固件基础上增加:
 *   - Wi-Fi 连接管理 (STA 模式, 初次配置 AP 模式)
 *   - Web 配置页面
 *   - ASCOM Alpaca FilterWheel HTTP API
 *   - mDNS 设备发现
 *
 * 编译: PlatformIO (env:esp8266) 或 Arduino IDE
 * 依赖: ESP8266WiFi, ESP8266WebServer, ESP8266mDNS, DNSServer
 */

#include <Arduino.h>
#include "hal.h"
#include "motion.h"
#include "wheel.h"
#include "transport.h"
#include "eeprom_config.h"

// ESP8266 特定头文件
#if defined(PLATFORM_ESP8266)
#include <ESP8266WiFi.h>
#include <ESP8266WebServer.h>
#include <ESP8266mDNS.h>
#include <DNSServer.h>
// #include <EEPROM.h>  已在 hal.cpp 中包含
#endif

/* =========================================================================
 * 网络配置
 * ========================================================================= */
#define WIFI_AP_SSID        "EFilterWheel-Setup"
#define WIFI_AP_PASSWORD    "filterwheel"
#define WIFI_CONNECT_TIMEOUT 15000   ///< Wi-Fi 连接超时 (ms)
#define MDNS_NAME           "efilterwheel"

// EEPROM 网络配置地址 (在 EEPROM_CONFIG_SIZE 之后)
#define EEPROM_WIFI_MAGIC   (EEPROM_CONFIG_SIZE + 0)
#define EEPROM_WIFI_SSID    (EEPROM_CONFIG_SIZE + 2)
#define EEPROM_WIFI_PASS    (EEPROM_CONFIG_SIZE + 34)
#define EEPROM_WIFI_MAGIC_VAL 0xBEEF

#if defined(PLATFORM_ESP8266)
static ESP8266WebServer server(80);
static DNSServer dnsServer;
static bool wifi_connected = false;
static bool ap_mode = false;
#endif

/* =========================================================================
 * 全局状态
 * ========================================================================= */
static uint32_t last_tick_ms = 0;

/* =========================================================================
 * Wi-Fi 管理 (ESP8266)
 * ========================================================================= */
#if defined(PLATFORM_ESP8266)

static void wifi_load_credentials(char* ssid, size_t ssid_len,
                                   char* pass, size_t pass_len)
{
    uint16_t magic = hal_eeprom_read_word(EEPROM_WIFI_MAGIC);
    if (magic != EEPROM_WIFI_MAGIC_VAL) {
        ssid[0] = '\0';
        pass[0] = '\0';
        return;
    }

    for (size_t i = 0; i < ssid_len - 1; i++) {
        ssid[i] = (char)hal_eeprom_read_byte(EEPROM_WIFI_SSID + i);
        if (ssid[i] == 0) break;
    }
    ssid[ssid_len - 1] = '\0';

    for (size_t i = 0; i < pass_len - 1; i++) {
        pass[i] = (char)hal_eeprom_read_byte(EEPROM_WIFI_PASS + i);
        if (pass[i] == 0) break;
    }
    pass[pass_len - 1] = '\0';
}

static void wifi_save_credentials(const char* ssid, const char* pass)
{
    hal_eeprom_write_word(EEPROM_WIFI_MAGIC, EEPROM_WIFI_MAGIC_VAL);

    size_t i;
    for (i = 0; i < 32 && ssid[i]; i++) {
        hal_eeprom_write_byte(EEPROM_WIFI_SSID + i, ssid[i]);
    }
    hal_eeprom_write_byte(EEPROM_WIFI_SSID + i, 0);

    for (i = 0; i < 32 && pass[i]; i++) {
        hal_eeprom_write_byte(EEPROM_WIFI_PASS + i, pass[i]);
    }
    hal_eeprom_write_byte(EEPROM_WIFI_PASS + i, 0);

    hal_eeprom_commit();
}

static void wifi_connect(void)
{
    char ssid[33] = {0};
    char pass[33] = {0};
    wifi_load_credentials(ssid, sizeof(ssid), pass, sizeof(pass));

    if (ssid[0] == '\0') {
        // 无保存的凭证，启动 AP 模式
        hal_serial_println("No WiFi credentials saved. Starting AP mode...");
        ap_mode = true;

        WiFi.mode(WIFI_AP);
        WiFi.softAP(WIFI_AP_SSID, WIFI_AP_PASSWORD);
        // 启动 DNS 劫持 (Captive Portal)
        dnsServer.start(53, "*", WiFi.softAPIP());

        hal_serial_print("AP IP: ");
        hal_serial_println(WiFi.softAPIP().toString().c_str());
        return;
    }

    // STA 模式连接
    ap_mode = false;
    WiFi.mode(WIFI_STA);
    WiFi.begin(ssid, pass);

    hal_serial_print("Connecting to WiFi: ");
    hal_serial_println(ssid);

    uint32_t start = millis();
    while (WiFi.status() != WL_CONNECTED) {
        if (millis() - start > WIFI_CONNECT_TIMEOUT) {
            hal_serial_println("WiFi connection timeout. Starting AP mode...");
            ap_mode = true;
            WiFi.mode(WIFI_AP);
            WiFi.softAP(WIFI_AP_SSID, WIFI_AP_PASSWORD);
            dnsServer.start(53, "*", WiFi.softAPIP());
            return;
        }
        hal_led_toggle();
        delay(500);
        hal_serial_print(".");
    }

    wifi_connected = true;
    hal_led_set(true);  // 常亮表示已连接
    hal_serial_println("");
    hal_serial_print("WiFi connected. IP: ");
    hal_serial_println(WiFi.localIP().toString().c_str());

    // mDNS
    if (MDNS.begin(MDNS_NAME)) {
        hal_serial_print("mDNS: http://");
        hal_serial_print(MDNS_NAME);
        hal_serial_println(".local");
        MDNS.addService("alpaca", "tcp", 80);
    }
}

/* =========================================================================
 * Web 服务器路由 (ESP8266)
 * ========================================================================= */

static void web_handle_root(void)
{
    String html = R"rawliteral(
<!DOCTYPE html>
<html lang="zh-CN">
<head>
<meta charset="UTF-8">
<meta name="viewport" content="width=device-width, initial-scale=1.0">
<title>EFilterWheel Control</title>
<style>
  body { font-family: Arial, sans-serif; max-width: 600px; margin: 0 auto; padding: 20px; background: #1a1a2e; color: #e0e0e0; }
  h1 { color: #00d4ff; }
  .card { background: #16213e; border-radius: 8px; padding: 15px; margin: 10px 0; }
  .btn { padding: 10px 20px; margin: 5px; border: none; border-radius: 5px; cursor: pointer; font-size: 14px; }
  .btn-home { background: #00d4ff; color: #000; }
  .btn-goto { background: #4caf50; color: #fff; }
  .btn-stop { background: #f44336; color: #fff; }
  .btn-save { background: #ff9800; color: #fff; }
  .btn:disabled { opacity: 0.5; cursor: not-allowed; }
  .status { font-size: 18px; padding: 10px; border-radius: 5px; }
  .ready { background: #1b5e20; }
  .moving { background: #e65100; }
  .error { background: #b71c1c; }
  .homing { background: #0d47a1; }
  input[type=number] { width: 60px; padding: 5px; font-size: 14px; }
  label { display: inline-block; width: 100px; }
</style>
</head>
<body>
<h1>🔭 EFilterWheel</h1>
<div class="card">
  <div id="status" class="status">Loading...</div>
  <p>Slot: <span id="pos">--</span></p>
  <p id="errorMsg"></p>
</div>
<div class="card">
  <h3>Control</h3>
  <button class="btn btn-home" onclick="sendCmd('HOME')">🏠 Home</button>
  <button class="btn btn-stop" onclick="sendCmd('STOP')">⏹ Stop</button>
  <br><br>
  <label>Go to slot:</label>
  <input type="number" id="slotNum" min="0" max="6" value="0">
  <button class="btn btn-goto" onclick="sendCmd('GOTO '+document.getElementById('slotNum').value)">➡ Go</button>
</div>
<div class="card">
  <h3>Settings</h3>
  <label>Slots:</label>
  <select id="slotsSelect" onchange="sendCmd('SLOTS '+this.value)">
    <option value="5">5</option>
    <option value="7" selected>7</option>
  </select>
  <br><br>
  <button class="btn btn-save" onclick="sendCmd('SAVE')">💾 Save Config</button>
  <button class="btn btn-save" onclick="sendCmd('RESET')">🔄 Reboot</button>
</div>
<script>
function sendCmd(cmd) {
  fetch('/api/cmd?c=' + encodeURIComponent(cmd))
    .then(r => r.text())
    .then(t => { console.log(t); refreshState(); });
}
function refreshState() {
  fetch('/api/state')
    .then(r => r.json())
    .then(s => {
      document.getElementById('status').textContent = s.State;
      document.getElementById('status').className = 'status ' + s.State.toLowerCase();
      document.getElementById('pos').textContent = s.Position;
      document.getElementById('errorMsg').textContent = s.ErrorCode ? 'Error: ' + s.ErrorMessage : '';
    });
}
setInterval(refreshState, 1000);
refreshState();
</script>
</body>
</html>
)rawliteral";
    server.send(200, "text/html; charset=utf-8", html);
}

static void web_handle_api_cmd(void)
{
    String cmd = server.arg("c");
    char buf[512];
    transport_set_output(TRANSPORT_OUTPUT_BUFFER, buf, sizeof(buf));
    transport_execute(cmd.c_str());
    server.send(200, "text/plain", buf);
}

static void web_handle_api_state(void)
{
    char buf[256];
    transport_get_state_json(buf, sizeof(buf));
    server.send(200, "application/json", buf);
}

static void web_handle_wifi_setup(void)
{
    if (server.method() == HTTP_POST) {
        String ssid = server.arg("ssid");
        String pass = server.arg("pass");
        if (ssid.length() > 0 && ssid.length() <= 32) {
            wifi_save_credentials(ssid.c_str(), pass.c_str());
            server.send(200, "text/html", "<h2>Saved! Rebooting...</h2><script>setTimeout(function(){location.href='/';},3000);</script>");
            delay(1000);
            hal_system_reset();
            return;
        }
    }

    String html = R"rawliteral(
<!DOCTYPE html>
<html><head><meta charset="UTF-8"><title>WiFi Setup</title>
<style>body{font-family:Arial;max-width:400px;margin:20px auto;background:#1a1a2e;color:#e0e0e0;}
.card{background:#16213e;border-radius:8px;padding:15px;}
input{width:100%;padding:8px;margin:5px 0;border-radius:4px;border:1px solid #333;background:#0f3460;color:#fff;}
.btn{background:#00d4ff;color:#000;padding:10px 20px;border:none;border-radius:5px;cursor:pointer;}</style>
</head><body>
<h2>WiFi Setup</h2>
<div class="card">
<form method="POST">
<label>SSID:</label><input name="ssid" required>
<label>Password:</label><input name="pass" type="password">
<button class="btn" type="submit">Save & Reboot</button>
</form>
</div>
</body></html>
)rawliteral";
    server.send(200, "text/html; charset=utf-8", html);
}

/* =========================================================================
 * Alpaca API 路由
 * ========================================================================= */

static void alpaca_handle_setup(void)
{
    server.send(200, "application/json",
        "{"
        "\"ServerName\":\"EFilterWheel\","
        "\"Manufacturer\":\"DIY\","
        "\"ServerVersion\":\"" FW_VERSION_STRING "\","
        "\"InterfaceVersion\":2"
        "}");
}

static void alpaca_handle_management(void)
{
    // Alpaca management API
    // GET /management/apiversions
    // GET /management/v1/description
    // GET /management/v1/configureddevices

    String uri = server.uri();
    if (uri.indexOf("apiversions") > 0) {
        server.send(200, "application/json", "[1,2]");
    } else if (uri.indexOf("description") > 0) {
        char buf[512];
        transport_get_device_info_json(buf, sizeof(buf));
        server.send(200, "application/json", buf);
    } else if (uri.indexOf("configureddevices") > 0) {
        server.send(200, "application/json",
            "[{\"DeviceName\":\"filterwheel\","
            "\"DeviceType\":\"FilterWheel\","
            "\"DeviceNumber\":0,"
            "\"UniqueID\":\"" DEVICE_NAME "\"}]");
    } else {
        server.send(404, "text/plain", "Not Found");
    }
}

static void alpaca_handle_filterwheel(void)
{
    // Alpaca FilterWheel API
    // GET  /api/v1/filterwheel/0/...
    // PUT  /api/v1/filterwheel/0/...

    String uri = server.uri();
    String method_str = (server.method() == HTTP_GET) ? "GET" : "PUT";

    if (uri.endsWith("/connected")) {
        if (method_str == "GET") {
            server.send(200, "application/json", "true");
        } else {
            server.send(200, "application/json", "true");
        }
    }
    else if (uri.endsWith("/name")) {
        char buf[64];
        snprintf(buf, sizeof(buf), "\"%s\"", DEVICE_NAME);
        server.send(200, "application/json", buf);
    }
    else if (uri.endsWith("/interfaceversion")) {
        server.send(200, "application/json", "2");
    }
    else if (uri.endsWith("/driverinfo")) {
        server.send(200, "application/json",
            "{\"Name\":\"EFilterWheel\","
            "\"Description\":\"DIY 3D-Printed Filter Wheel\","
            "\"DriverVersion\":\"" FW_VERSION_STRING "\","
            "\"InterfaceVersion\":2}");
    }
    else if (uri.endsWith("/position")) {
        if (method_str == "GET") {
            int8_t pos = wheel_get_current_slot();
            char buf[8];
            snprintf(buf, sizeof(buf), "%d", (int)pos);
            server.send(200, "application/json", buf);
        } else {
            // PUT: 设置位置
            String body = server.arg("plain");
            int slot = body.toInt();
            if (wheel_goto_slot((uint8_t)slot)) {
                server.send(200, "application/json", "{}");
            } else {
                server.send(400, "text/plain", "Invalid slot");
            }
        }
    }
    else if (uri.endsWith("/names")) {
        const wheel_config_t* cfg = wheel_get_config();
        String json = "[";
        for (uint8_t i = 0; i < cfg->num_slots; i++) {
            if (i > 0) json += ",";
            json += "\"";
            json += cfg->slot_names[i];
            json += "\"";
        }
        json += "]";
        server.send(200, "application/json", json);
    }
    else if (uri.endsWith("/focusoffsets")) {
        const wheel_config_t* cfg = wheel_get_config();
        String json = "[";
        for (uint8_t i = 0; i < cfg->num_slots; i++) {
            if (i > 0) json += ",";
            json += String(cfg->focus_offsets[i]);
        }
        json += "]";
        server.send(200, "application/json", json);
    }
    else if (uri.endsWith("/supportedactions")) {
        server.send(200, "application/json", "[]");
    }
    else {
        server.send(404, "text/plain", "Not Found");
    }
}

static void web_setup_routes(void)
{
    server.on("/", web_handle_root);
    server.on("/api/cmd", web_handle_api_cmd);
    server.on("/api/state", web_handle_api_state);
    server.on("/wifi", web_handle_wifi_setup);

    // Alpaca management
    server.on("/management/apiversions", alpaca_handle_management);
    server.on("/management/v1/description", alpaca_handle_management);
    server.on("/management/v1/configureddevices", alpaca_handle_management);

    // Alpaca FilterWheel API
    // 使用通配符处理动态路径
    server.on("/api/v1/filterwheel/0/connected", alpaca_handle_filterwheel);
    server.on("/api/v1/filterwheel/0/name", alpaca_handle_filterwheel);
    server.on("/api/v1/filterwheel/0/interfaceversion", alpaca_handle_filterwheel);
    server.on("/api/v1/filterwheel/0/driverinfo", alpaca_handle_filterwheel);
    server.on("/api/v1/filterwheel/0/position", alpaca_handle_filterwheel);
    server.on("/api/v1/filterwheel/0/names", alpaca_handle_filterwheel);
    server.on("/api/v1/filterwheel/0/focusoffsets", alpaca_handle_filterwheel);
    server.on("/api/v1/filterwheel/0/supportedactions", alpaca_handle_filterwheel);
}

#endif // PLATFORM_ESP8266

/* =========================================================================
 * 初始化
 * ========================================================================= */
void setup(void)
{
    // 1. 硬件初始化
    hal_init();

    // 2. 延时
    hal_delay_ms(500);

    // 3. 启动提示
    hal_buzzer_play_startup();

    // 4. 子系统初始化
    motion_init();
    transport_init();
    wheel_init();

    // 5. 看门狗 (ESP8266 由 SDK 管理，Nano 使用 WDT)
    hal_wdt_enable(8);

    // 6. 启动信息
    hal_serial_println("");
    hal_serial_println("==============================");
    hal_serial_print("EFilterWheel-ESP8266 FW ");
    hal_serial_println(FW_VERSION_STRING);
    hal_serial_println("==============================");

#if defined(PLATFORM_ESP8266)
    // 7. Wi-Fi 初始化
    wifi_connect();

    // 8. Web 服务器路由
    web_setup_routes();
    server.begin();
    hal_serial_println("HTTP server started on port 80");
#endif

    // 9. 自动回零
    hal_serial_println("Starting auto-homing...");
    wheel_start_homing();
}

/* =========================================================================
 * 主循环
 * ========================================================================= */
void loop(void)
{
    uint32_t now = hal_millis();

    // 1. 定时 tick
    if ((int32_t)(now - last_tick_ms) >= 1) {
        last_tick_ms = now;
        hal_tick_process();
    }

    // 2. 状态机
    wheel_tick();

    // 3. 运动超时
    motion_tick();

    // 4. 串口命令
    transport_tick();

    // 5. 空闲释放电机
    motion_release_if_idle();

#if defined(PLATFORM_ESP8266)
    // 6. Web 服务器处理
    server.handleClient();

    // 7. DNS 劫持 (AP 模式)
    if (ap_mode) {
        dnsServer.processNextRequest();
    }

    // 8. mDNS 更新
    if (wifi_connected) {
        MDNS.update();
    }

    // 9. 检查 Wi-Fi 断线重连
    if (!ap_mode && WiFi.status() != WL_CONNECTED) {
        wifi_connected = false;
        hal_led_blink_pattern(0, 500, 500);
        // 尝试重连
        WiFi.reconnect();
    }
#endif

    // 10. 平台 yield（ESP8266 喂狗等）
    hal_platform_yield();
}

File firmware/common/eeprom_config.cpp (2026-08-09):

/**
 * @file eeprom_config.cpp
 * @brief EEPROM 配置存储实现
 */

#include "eeprom_config.h"
#include "hal.h"
#include <stdio.h>
#include <string.h>

/* =========================================================================
 * 内部辅助
 * ========================================================================= */

/// 计算配置数据的简单校验和（XOR）
static uint8_t calc_checksum(const wheel_config_t* cfg)
{
    const uint8_t* ptr = (const uint8_t*)cfg;
    uint8_t sum = 0x55;
    for (uint16_t i = 0; i < sizeof(wheel_config_t); i++) {
        sum ^= ptr[i];
    }
    return sum;
}

/* =========================================================================
 * 公共 API
 * ========================================================================= */

void eeprom_config_init(void)
{
    // EEPROM 在 hal_init 中已初始化
    // 这里预留扩展空间
}

bool eeprom_config_is_valid(void)
{
    uint16_t magic = hal_eeprom_read_word(EEPROM_MAGIC_ADDR);
    return (magic == EEPROM_MAGIC);
}

void eeprom_config_defaults(wheel_config_t* cfg)
{
    memset(cfg, 0, sizeof(wheel_config_t));

    cfg->num_slots   = DEFAULT_SLOTS;
    cfg->speed_pps   = DEFAULT_SPEED_PPS;
    cfg->default_dir = DIR_CW;
    cfg->invert_dir  = false;
    cfg->home_offset = 0;

    // 均匀分布槽位步数（后续由标定程序填充精确值）
    // 假设一圈的总步数约为 4096（28BYJ-48: 64*63.7≈4076）
    uint16_t full_circle = 4096;
    for (uint8_t i = 0; i < MAX_SLOTS; i++) {
        cfg->slot_steps[i]   = (uint32_t)full_circle * i / cfg->num_slots;
        cfg->focus_offsets[i] = 0;
        snprintf(cfg->slot_names[i], sizeof(cfg->slot_names[0]),
                 "Slot %d", i + 1);
    }
}

bool eeprom_config_load(wheel_config_t* cfg)
{
    if (!eeprom_config_is_valid()) {
        eeprom_config_defaults(cfg);
        return false;
    }

    // 校验版本
    uint8_t stored_version = hal_eeprom_read_byte(EEPROM_VERSION_ADDR);
    uint8_t stored_checksum = hal_eeprom_read_byte(EEPROM_CHECKSUM_ADDR);
    (void)stored_version;  // 保留用于未来版本迁移

    // 从 EEPROM 读出原始字节
    uint8_t* raw = (uint8_t*)cfg;
    uint16_t addr = EEPROM_SLOTS_ADDR;
    for (uint16_t i = 0; i < sizeof(wheel_config_t); i++) {
        raw[i] = hal_eeprom_read_byte(addr + i);
    }

    // 校验和验证
    uint8_t computed = calc_checksum(cfg);
    if (computed != stored_checksum) {
        eeprom_config_defaults(cfg);
        return false;
    }

    // 范围检查
    if (cfg->num_slots < MIN_SLOTS || cfg->num_slots > MAX_SLOTS) {
        eeprom_config_defaults(cfg);
        return false;
    }

    if (cfg->speed_pps < MIN_SPEED_PPS || cfg->speed_pps > MAX_SPEED_PPS) {
        cfg->speed_pps = DEFAULT_SPEED_PPS;
    }

    return true;
}

bool eeprom_config_save(const wheel_config_t* cfg)
{
    if (!cfg) return false;

    // 写入魔数
    hal_eeprom_write_word(EEPROM_MAGIC_ADDR, EEPROM_MAGIC);
    hal_eeprom_write_byte(EEPROM_VERSION_ADDR, 1);  // 配置版本 1
    hal_eeprom_write_byte(EEPROM_CHECKSUM_ADDR, calc_checksum(cfg));

    // 写入配置数据
    const uint8_t* raw = (const uint8_t*)cfg;
    uint16_t addr = EEPROM_SLOTS_ADDR;
    for (uint16_t i = 0; i < sizeof(wheel_config_t); i++) {
        hal_eeprom_write_byte(addr + i, raw[i]);
    }

    hal_eeprom_commit();
    return true;
}

void eeprom_config_factory_reset(void)
{
    // 擦除魔数标记，下次加载时自动使用默认值
    hal_eeprom_write_word(EEPROM_MAGIC_ADDR, 0x0000);
    hal_eeprom_commit();
}

uint16_t eeprom_config_get_slot_steps(uint8_t slot)
{
    if (slot >= MAX_SLOTS) return 0;
    uint16_t addr = EEPROM_SLOT_STEPS + slot * 2;
    return hal_eeprom_read_word(addr);
}

void eeprom_config_set_slot_steps(uint8_t slot, uint16_t steps)
{
    if (slot >= MAX_SLOTS) return;
    uint16_t addr = EEPROM_SLOT_STEPS + slot * 2;
    hal_eeprom_write_word(addr, steps);
}

uint16_t eeprom_config_get_full_circle_steps(void)
{
    // 从 EEPROM 加载配置获取
    wheel_config_t cfg;
    if (eeprom_config_load(&cfg)) {
        if (cfg.num_slots > 0) {
            // 槽位 0 到槽位 0 即一整圈
            // 最后一个槽位步数 + (一圈步数 - 最后一个槽位步数)
            // 简化：如果标定过，从 slot_steps 推算
            return cfg.slot_steps[cfg.num_slots - 1] * cfg.num_slots
                   / (cfg.num_slots - 1);
        }
    }
    return 4096;  // 默认 28BYJ-48 一圈步数
}

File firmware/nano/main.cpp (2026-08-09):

/**
 * @file main.cpp
 * @brief Arduino Nano 滤镜轮固件入口
 *
 * 编译: PlatformIO (env:nano) 或 Arduino IDE
 *
 * 主循环流程:
 *   1. 初始化 HAL、运动、滤镜轮、传输层
 *   2. 进入主循环:
 *      - 处理传感器更新和后台 tick
 *      - 处理滤镜轮状态机
 *      - 处理串口命令
 *      - 喂狗
 */

#include <Arduino.h>
#include "hal.h"
#include "motion.h"
#include "wheel.h"
#include "transport.h"
#include "eeprom_config.h"

/* =========================================================================
 * 全局 tick 计数器
 * ========================================================================= */
static uint32_t last_tick_ms = 0;

/* =========================================================================
 * 初始化
 * ========================================================================= */
void setup(void)
{
    // 1. 硬件初始化
    hal_init();

    // 2. 简短延时让串口稳定
    hal_delay_ms(500);

    // 3. 播放启动提示
    hal_buzzer_play_startup();

    // 4. 初始化各子系统
    motion_init();
    transport_init();
    wheel_init();

    // 5. 使能看门狗 (4s)
    hal_wdt_enable(4);

    // 6. 发送启动信息
    hal_serial_println("");
    hal_serial_println("==============================");
    hal_serial_print("EFilterWheel-Nano FW ");
    hal_serial_println(FW_VERSION_STRING);
    hal_serial_println("==============================");
    hal_serial_print("Config loaded: ");
    hal_serial_println(eeprom_config_is_valid() ? "YES" : "NO (using defaults)");

    // 7. 自动开始回零
    hal_serial_println("Starting auto-homing...");
    wheel_start_homing();
}

/* =========================================================================
 * 主循环
 * ========================================================================= */
void loop(void)
{
    uint32_t now = hal_millis();

    // 1. 传感器更新 + LED 闪烁（每个 tick）
    if ((int32_t)(now - last_tick_ms) >= 1) {
        last_tick_ms = now;
        hal_tick_process();

        // 检查霍尔传感器状态用于诊断
        // (实际值由 hal_sensors_update 更新)
    }

    // 2. 滤镜轮状态机
    wheel_tick();

    // 3. 运动层超时检查
    motion_tick();

    // 4. 串口命令处理
    transport_tick();

    // 5. 空闲时释放电机
    motion_release_if_idle();

    // 6. 喂狗
    hal_wdt_reset();
}

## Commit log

2026-07-17 feat: EFilterWheel initial commit - dual-platform firmware + 3D models + BOM
    - Arduino Nano / ESP8266 firmware with 4-layer architecture (hal/motion/wheel/transport)
    - ASCII serial protocol + ASCOM Alpaca HTTP API
    - 14 STL 3D print models + 3MF slicing config
    - BOM Excel + PCB Gerber files
    - avrdude flashing tools
    - Assembly reference images
    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
    [AstroFilterWheel_BOM & 物料统计_2025-08-09.xlsx, PCB螺丝垫片.STL, 传动轮2_D轴.STL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]
2026-07-17 docs: ESP8266 wiring guide + STL dimension analysis tool
    - README: add ESP8266 pin mapping, level conversion guide, soldering steps
    - README: explain why open-collector sensors need no level shifter
    - tools/stl2step.py: STL dimension extraction with CSV/individual reports
    - ref/step/: 13 part dimension reports + summary CSV
    [dimensions.csv]
2026-08-09 fix(firmware): restore cross-platform builds
    Declare shared dependencies explicitly and schedule ESP8266 motor steps from the main loop to avoid unsafe timer callbacks.
    [config.h, eeprom_config.cpp, hal.cpp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]
